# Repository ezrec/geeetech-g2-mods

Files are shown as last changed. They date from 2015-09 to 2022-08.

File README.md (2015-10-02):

# Geeetech Delta Rostock G2/G2s

## OpenSCAD versions of Geeetech STLs (Geeetech)

`geeetech_rostock_g2_jhead_x1.scad` - Upper and lower brackets for G2
`geeetech_rostock_g2_jhead_x2.scad` - Upper and lower brackets for G2s
`geeetech_rostock_g2_spider.scad` - Spider (with optional Z-Probe)
`geeetech_rostock_g2_lock_ring.scad` - Z-Probe lock ring

## Mechanics Modifications

`rod_end_shim.scad` - Shim washers to remove slop in the rod-end mounts

## MK8 Extruder Modifications

`mk8_extruder_guide.scad` - Snap-in guide for the lower feed of the MK8 Extruder

## Alternative Spider Effectors

`cimera-spider.scad` - Spider for E3D Chimera/Cyclops hot ends

## Fan Ducts

`e3d_v6_fan_duct.scad` - Hot-air fan duct for a E3D v6 or v6Lite mounted on a G2 Spider
`universal_fan_duct.scad` - Universal cool-air fan duct for E3D v6 or J-Head, single or dual mount - mounts instead of Z-Probe switch!

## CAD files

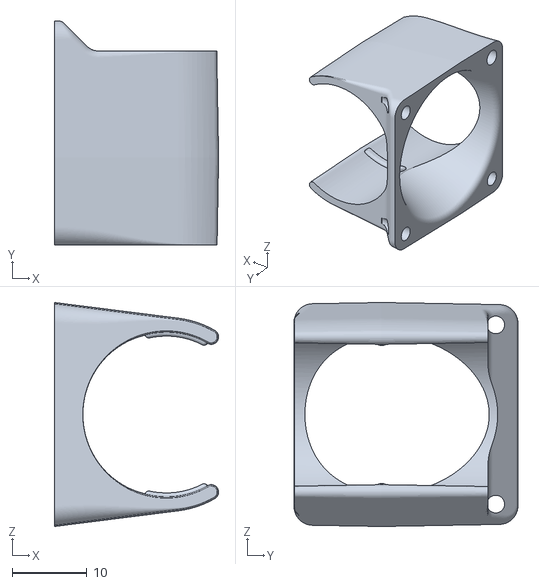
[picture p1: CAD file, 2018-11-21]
E3D/V6.6_Duct.stl
22.0 x 30.0 x 30.0

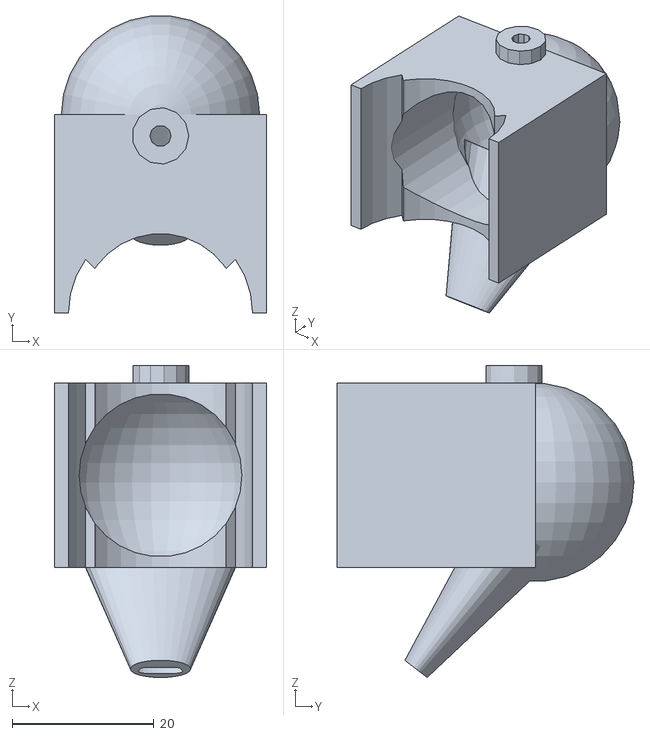
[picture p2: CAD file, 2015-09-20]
e3d_v6_fan_duct.stl
30.0 x 41.9 x 44.1

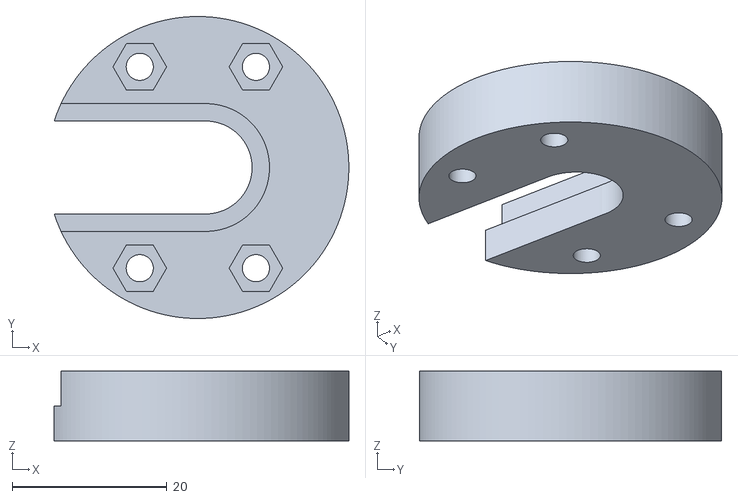
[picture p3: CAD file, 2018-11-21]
Geeetech/G2/GTH3-B01-02-Mount.STL
38.0 x 39.0 x 9.00

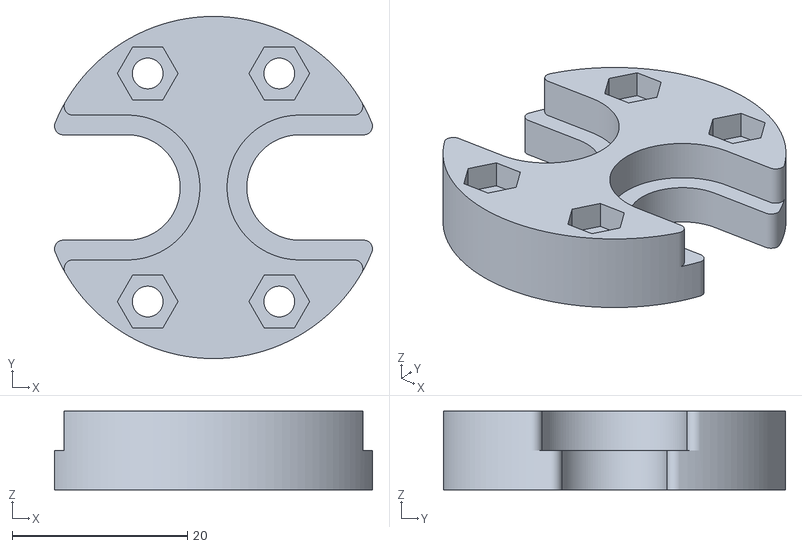
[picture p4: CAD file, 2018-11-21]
Geeetech/G2s/GTH3-B02-02-Mount.STL
36.2 x 39.0 x 9.00

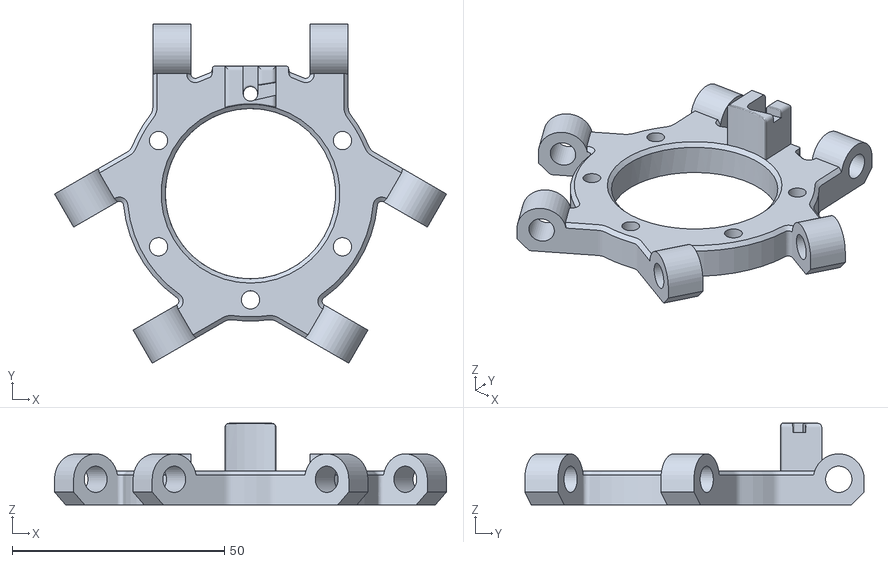
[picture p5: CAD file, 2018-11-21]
Geeetech/RKMA-B02-platform.STL
92.3 x 79.9 x 19.2

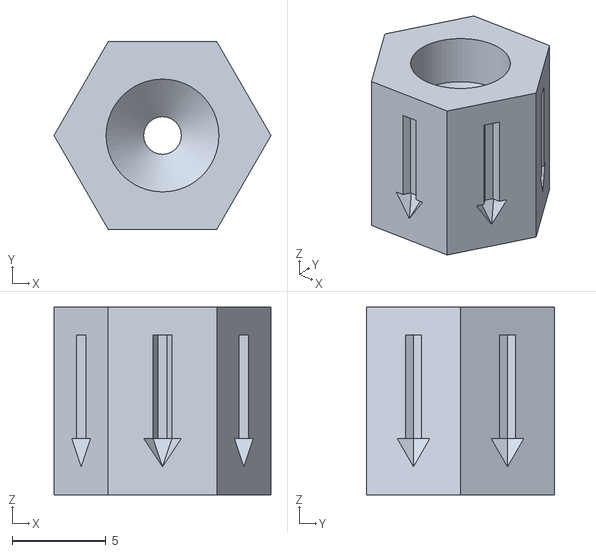
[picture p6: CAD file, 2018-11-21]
stl/ptfe_splicer.stl
11.5 x 10.0 x 10.0

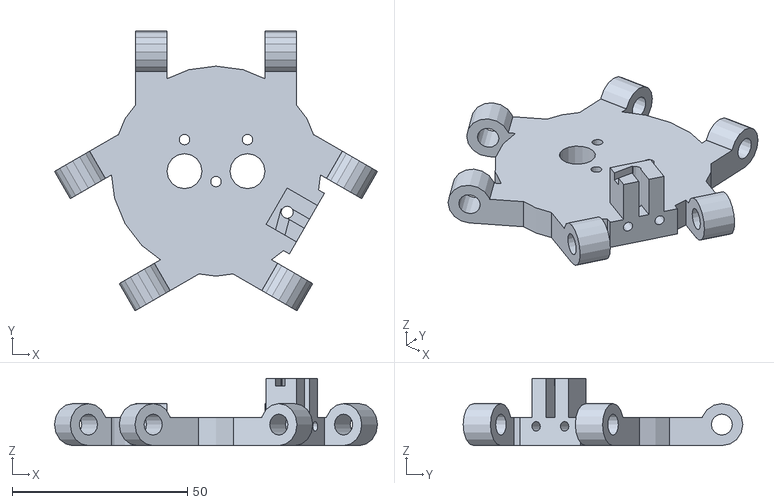
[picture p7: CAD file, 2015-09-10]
chimera-spider.stl
92.3 x 79.9 x 19.2

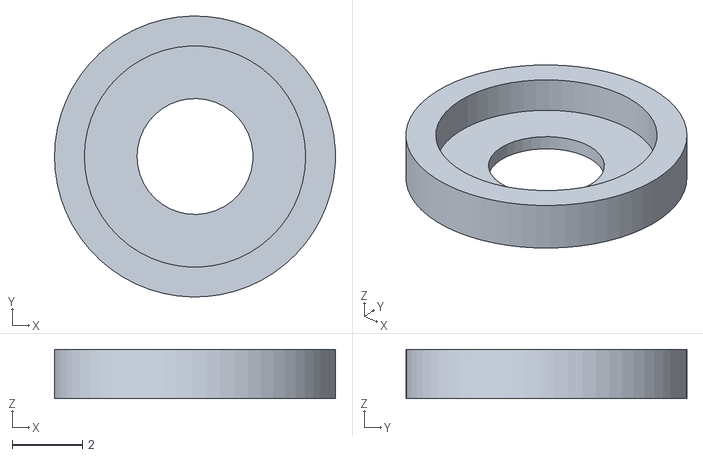
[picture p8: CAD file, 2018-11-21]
Geeetech/G2/RKMC-B01-check ring.STL
8.00 x 8.00 x 1.40

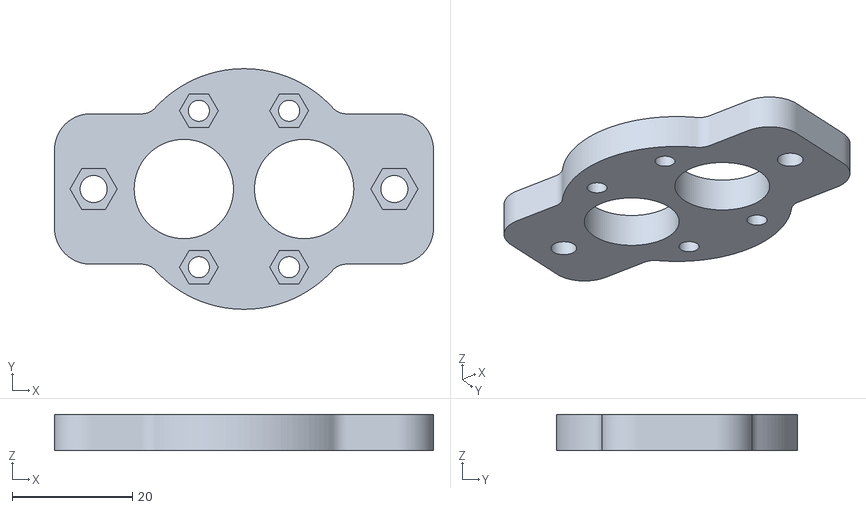
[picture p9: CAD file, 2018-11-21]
Geeetech/G2s/GTH3-B02-01-Mount.STL
63.0 x 40.0 x 6.00

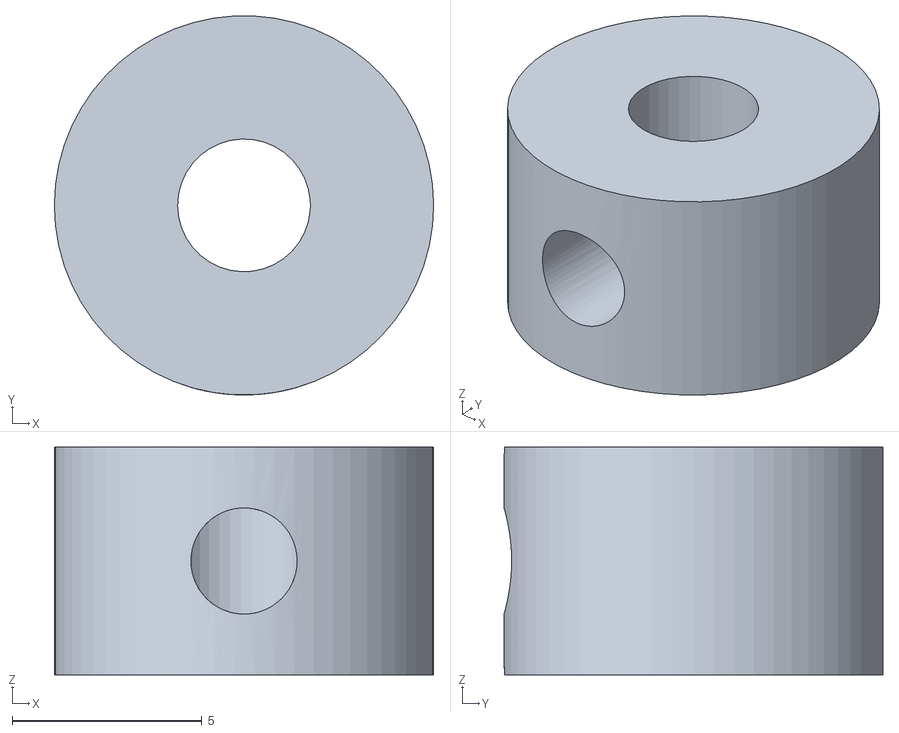
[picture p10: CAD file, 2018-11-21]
Geeetech/RKMA-B05-Lock rings.STL
10.0 x 9.99 x 6.00

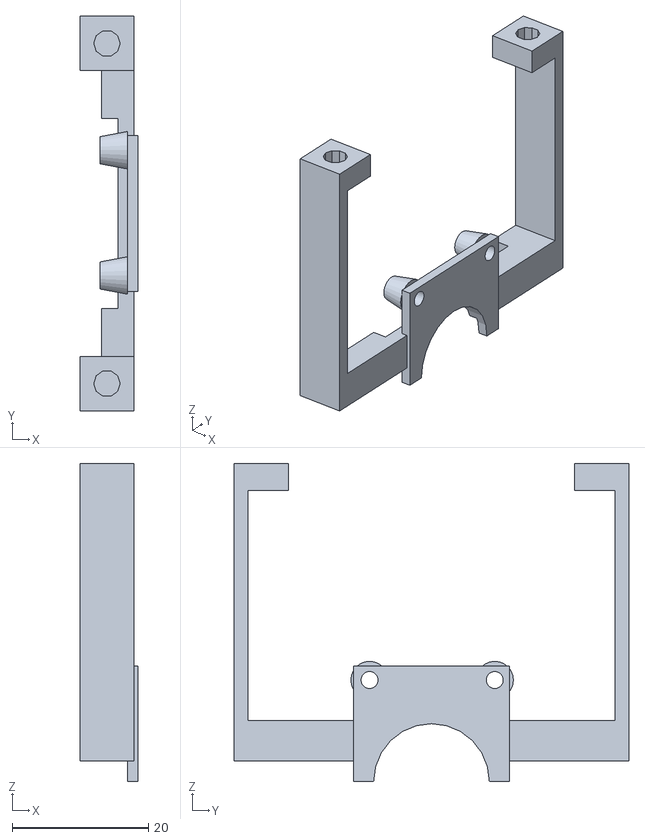
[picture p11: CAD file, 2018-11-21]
stl/universal_probe.stl
8.60 x 58.0 x 46.8

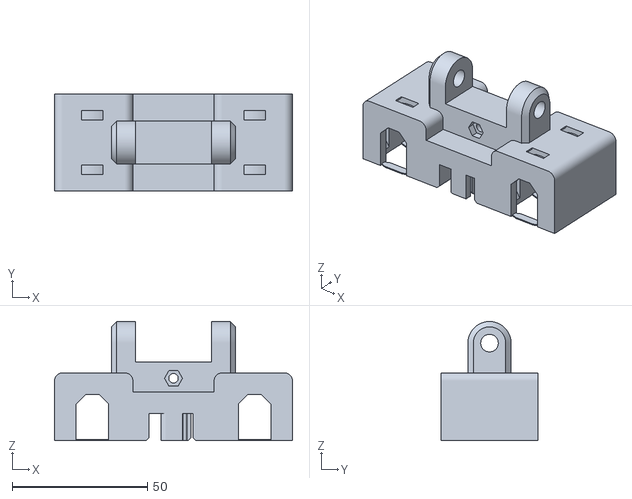
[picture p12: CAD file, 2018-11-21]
Geeetech/RKMA-B01-carriage.STL
88.0 x 36.0 x 44.0

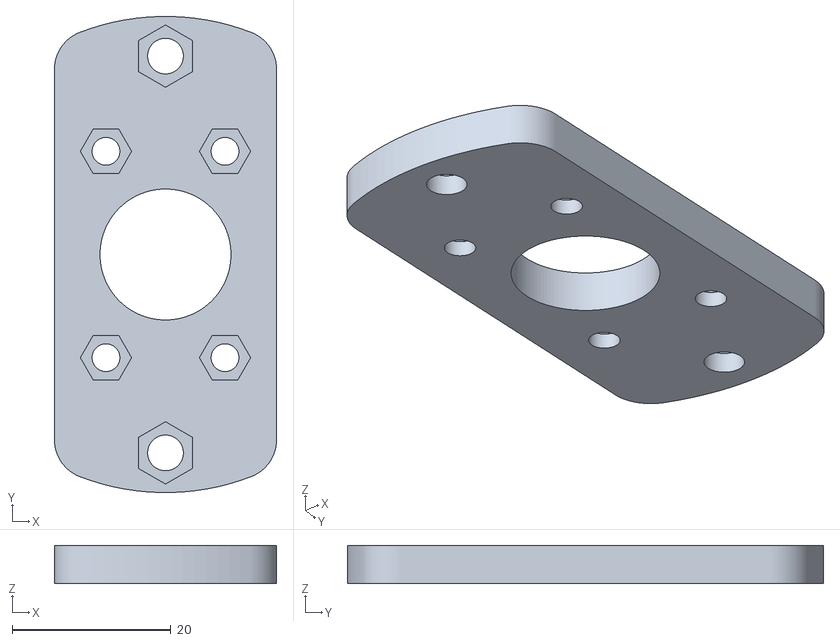
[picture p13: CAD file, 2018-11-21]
Geeetech/G2/GTH3-B01-01-Mount.STL
28.0 x 60.0 x 4.80

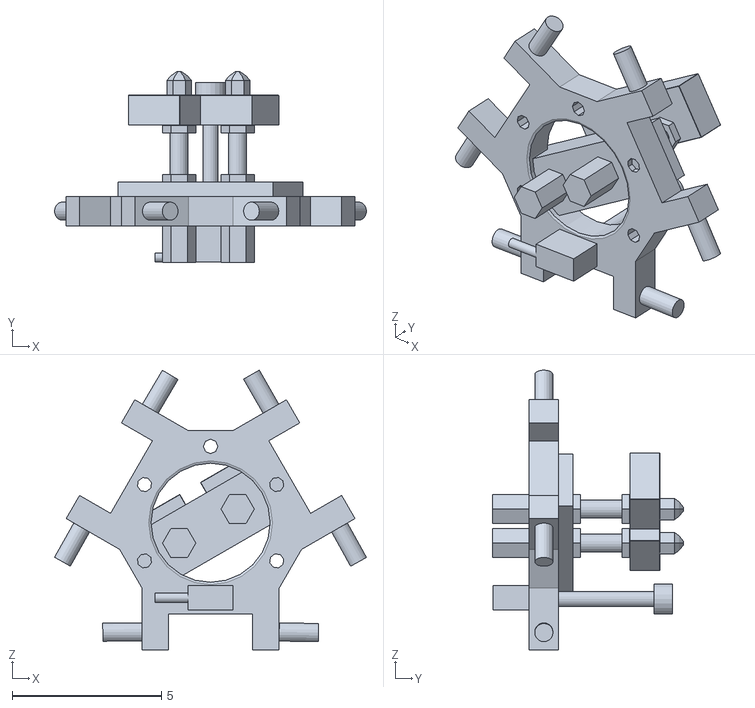
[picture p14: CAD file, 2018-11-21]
Geeetech/PRO_SPIDER.stl
10.5 x 6.41 x 9.37

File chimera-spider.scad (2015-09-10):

//
// Copyright (C) 2015, Jason S. McMullan <jason.mcmullan@gmail.com>
// All right reserved.
//
// Licensed under the MIT License:
//
// Permission is hereby granted, free of charge, to any person obtaining
// a copy of this software and associated documentation files (the "Software"),
// to deal in the Software without restriction, including without limitation
// the rights to use, copy, modify, merge, publish, distribute, sublicense,
// and/or sell copies of the Software, and to permit persons to whom the
// Software is furnished to do so, subject to the following conditions:
//
// The above copyright notice and this permission notice shall be included
// in all copies or substantial portions of the Software.
//
// THE SOFTWARE IS PROVIDED "AS IS", WITHOUT WARRANTY OF ANY KIND, EXPRESS OR
// IMPLIED, INCLUDING BUT NOT LIMITED TO THE WARRANTIES OF MERCHANTABILITY,
// FITNESS FOR A PARTICULAR PURPOSE AND NONINFRINGEMENT. IN NO EVENT SHALL THE
// AUTHORS OR COPYRIGHT HOLDERS BE LIABLE FOR ANY CLAIM, DAMAGES OR OTHER
// LIABILITY, WHETHER IN AN ACTION OF CONTRACT, TORT OR OTHERWISE, ARISING
// FROM, OUT OF OR IN CONNECTION WITH THE SOFTWARE OR THE USE OR OTHER
// DEALINGS IN THE SOFTWARE.
//

include <E3D/chimera.scad>
include <Geeetech/rostock_g2_spider.scad>

module geeetech_spider_e3d_chimera(zprobe = true)
{
    difference() {
        union() {
            rotate([0, 0, 240])
            geeetech_rostock_g2_spider_blank(zprobe);
        }
        translate([-9, 0, -0.1])
            cylinder(d=10, h=10, $fn=16);
        translate([9, 0, -0.1])
            cylinder(d=10, h=10, $fn=16);
        translate([0, -3, -0.1])
            cylinder(d=3, h=10, $fn=16);
        translate([-9, 9, -0.1])
            cylinder(d=3, h=10, $fn=16);
        translate([9, 9, -0.1])
            cylinder(d=3, h=10, $fn=16);
    }

    % translate([-15, -6, 0])     e3d_v6_chimera();
}


geeetech_spider_e3d_chimera();

// vim: set shiftwidth=4 expandtab: //

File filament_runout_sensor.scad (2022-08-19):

//
// Copyright 2019 Barrett Ford <https://www.thingiverse.com/barrettford/about>
//
// https://www.thingiverse.com/thing:3052714
//

$fa=.5;
$fs=1;
$fn=60;

module switch() {
  difference() {
    union() {
      translate([0,-3.3,0]) cube([10, 6.6, 9.5]);
      translate([-10,-3.3,0]) cube([10, 6.6, 10.3]);
      
      translate([-7,-3.3,10.5]) rotate([0,70,0]) cube([7, 6.6, 21]);
    }
    translate([5, 4, 2.6]) rotate([90,0,0]) cylinder(d=3,h=8);
    translate([-5, 4, 2.6]) rotate([90,0,0]) cylinder(d=3,h=8);
  }
  hull() {
    translate([10.7 , 3.3, 15.5]) rotate([90,0,0]) cylinder(d=5,h=6.6);
    translate([10.35, 3.3, 17.0]) rotate([90,0,0]) cylinder(d=5,h=6.6);
    translate([10.0 , 3.3, 18.5]) rotate([90,0,0]) cylinder(d=5,h=6.6);
    translate([9.65 , 3.3, 19.5]) rotate([90,0,0]) cylinder(d=5,h=6.6);
  }
}


module bottom() {
  height = 9;
  tube_diameter = 4.2;
  difference() {
    union() {
      translate([1.5,0,0]) hull()
      {
        translate([-12,5.5,2.5])  rotate([90,0,0]) cylinder(d=5, h=height);
        translate([ 12,5.5,2.5])  rotate([90,0,0]) cylinder(d=5, h=height);
        translate([-18,5.5,27.5]) rotate([90,0,0]) cylinder(d=5, h=height);
        translate([ 18,5.5,27.5]) rotate([90,0,0]) cylinder(d=5, h=height);
        
      }
    }
    translate([-25,0,25]) rotate([0,90,0]) cylinder(d=tube_diameter, h=50);
    translate([-11,-6.5,-1]) cube([22, 10, 21]);
    translate([ 5,-6.5, 10]) cube([11, 10, 16]);
    
    hull() {
      translate([5, 6, 3.6]) rotate([90,0,0]) cylinder(d=3,h=20);
      translate([5, 6, 10]) rotate([90,0,0]) cylinder(d=3,h=20);
    }
    
    hull() {
      translate([-5, 6, 3.6]) rotate([90,0,0]) cylinder(d=3,h=20);
      translate([-5, 6, 10]) rotate([90,0,0]) cylinder(d=3,h=20);
    }
  }
}

// Uncomment this line to see where the switch would fit
//translate([0,0,5]) #switch();
bottom();

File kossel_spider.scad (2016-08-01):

//
// Copyright (C) 2016, Jason S. McMullan <jason.mcmullan@gmail.com>
// All rights reserved.
//
// Generic Kossel effector.
//
// Licensed under the MIT License:
//
// Permission is hereby granted, free of charge, to any person obtaining
// a copy of this software and associated documentation files (the "Software"),
// to deal in the Software without restriction, including without limitation
// the rights to use, copy, modify, merge, publish, distribute, sublicense,
// and/or sell copies of the Software, and to permit persons to whom the
// Software is furnished to do so, subject to the following conditions:
//
// The above copyright notice and this permission notice shall be included
// in all copies or substantial portions of the Software.
//
// THE SOFTWARE IS PROVIDED "AS IS", WITHOUT WARRANTY OF ANY KIND, EXPRESS OR
// IMPLIED, INCLUDING BUT NOT LIMITED TO THE WARRANTIES OF MERCHANTABILITY,
// FITNESS FOR A PARTICULAR PURPOSE AND NONINFRINGEMENT. IN NO EVENT SHALL THE
// AUTHORS OR COPYRIGHT HOLDERS BE LIABLE FOR ANY CLAIM, DAMAGES OR OTHER
// LIABILITY, WHETHER IN AN ACTION OF CONTRACT, TORT OR OTHERWISE, ARISING
// FROM, OUT OF OR IN CONNECTION WITH THE SOFTWARE OR THE USE OR OTHER
// DEALINGS IN THE SOFTWARE.
//
// All units are in mm

// Adjust the scaler for quick twist lock tolerance-only prints 
scaler = 1;

/* [Delta Geometry] */

// Distance from center of effector to center of diagnal rod axis
effector_radius = 34; // [10:100]

// Distance between effector rod ends
effector_width = 46; // [10:100]

// Height of the effector frame
effector_height = 8;

/* [Diagonal Rod Mount] */

// Diameter of the rod end holder
effector_holder_diameter = 6; // [1:20]

// Width of the wall of the rod end holder
effector_holder_wall = 3.5; // [1:10]

// Length of the rod end holder hole
effector_holder_hole = 9; // [1:20]

/* [Effector Mount] */

// Flat-to-flat diameter of the internal hex mount
effector_mount_hex = 40; // [0:100]

/* [Hotend Lock] */

// Hotend model
hotend_model=0; // [0:E3D v6,1:J-Head,2:Custom Groovemount]

// Minimum wall size around the hotend in mm
hotend_wall = 2; // [1:5]

// Hotend bulk diameter
custom_hotend_diameter = 20;
custom_hotend_height = 30;
custom_hotend_groove_diameter = 12;
custom_hotend_groove_height = 3;
custom_hotend_inlet_diameter = 16;
custom_hotend_shoulder_diameter = 16;
custom_hotend_shoulder_height = 6;

// E3D v6
e3dv6_hotend_diameter = 22;
e3dv6_hotend_height = 31.5;
e3dv6_hotend_groove_diameter = 12;
e3dv6_hotend_groove_height = 6;
e3dv6_hotend_inlet_diameter = 16;
e3dv6_hotend_shoulder_diameter = 16;
e3dv6_hotend_shoulder_height = 6;

// J-Head
jhead_hotend_diameter = 16;
jhead_hotend_height = 29;
jhead_hotend_groove_diameter = 12;
jhead_hotend_groove_height = 4.5;
jhead_hotend_inlet_diameter = 16;
jhead_hotend_shoulder_diameter = 16;
jhead_hotend_shoulder_height = 0;

hotend_diameter = (hotend_model == 0 ? e3dv6_hotend_diameter :
                  (hotend_model == 1 ? jhead_hotend_diameter :
                   custom_hotend_diameter));
hotend_height =  (hotend_model == 0 ? e3dv6_hotend_height :
                 (hotend_model == 1 ? jhead_hotend_height :
                  custom_hotend_height));
hotend_groove_diameter = (hotend_model == 0 ? e3dv6_hotend_groove_diameter :
                 (hotend_model == 1 ? jhead_hotend_groove_diameter :
                  custom_hotend_groove_diameter));
hotend_groove_height = (hotend_model == 0 ? e3dv6_hotend_groove_height :
                 (hotend_model == 1 ? jhead_hotend_groove_height :
                  custom_hotend_groove_height));
hotend_inlet_diameter = (hotend_model == 0 ? e3dv6_hotend_inlet_diameter :
                 (hotend_model == 1 ? jhead_hotend_inlet_diameter :
                  custom_hotend_inlet_diameter));
hotend_shoulder_diameter = (hotend_model == 0 ? e3dv6_hotend_shoulder_diameter :
                 (hotend_model == 1 ? jhead_hotend_shoulder_diameter :
                  custom_hotend_shoulder_diameter));
hotend_shoulder_height = (hotend_model == 0 ? e3dv6_hotend_shoulder_height :
                 (hotend_model == 1 ? jhead_hotend_shoulder_height :
                  custom_hotend_shoulder_height));


hotend_radius = hotend_diameter/2;

hotend_lock_brim = 1.5; // [0.25:5]
hotend_lock_height = effector_height - hotend_wall*2;

// Critical dimensions of the lock - 'maximum' lock size
hotend_lock_radius   = e3dv6_hotend_diameter/2+hotend_wall;
hotend_lock_distance = e3dv6_hotend_diameter+hotend_wall;

/* [Fan Dimensions] */
fan_width = 30; // [10:40]

/* [ Global ] */

// Screw size
screw_width = 2.6;
screw_depth = 5.75;
screw_gap = 24.5;

// Twist-lock lock_tolerance
lock_tolerance = 0.25 / scaler;
// Hole tolerance
hole_tolerance = 0.125 / scaler;

// Faces for cylinders
fn = 60; // [6:60]

fan_radius = fan_width/2-hotend_wall;

// WhosaWhatsis Hull Chain
module hull_chain()
{
    for (i = [0 : $children - 2]) hull() for(j = [i, i+1]) children(j);
}


module round_hole(r = 1, h = 1, centered = false, fn = fn)
{
    if (centered) {
        translate([0, 0, -h/2-0.1])
            cylinder(r = r + hole_tolerance, h = h + 0.2, $fn = fn);
    } else {
        translate([0, 0, -0.1])
            cylinder(r = r + hole_tolerance, h = h + 0.2, $fn = fn);
    }
}

// 2D Measurement graphic
module measure(distance = 5, unit = "n")
{
    thickness = 0.2;
    length = 2;
    text_height = 1;
    text_length = 3;

    text(str(distance,unit), halign = "center", valign = "bottom", size = text_height);
}

module hotend_cut(tolerance = lock_tolerance)
{
    translate([0, 0, -0.1])
    rotate_extrude(angle = 360, $fn = fn) {
        intersection() {
            offset(delta = tolerance, chamfer = true) {
                /* Build radius profile of hotend from bottom up */
                
                /* Body */
                square([hotend_radius, hotend_height-hotend_shoulder_height+0.1]);
                translate([0, hotend_height-hotend_shoulder_height+0.1]) {
                    square([hotend_shoulder_diameter/2, hotend_shoulder_height]);
                    translate([0, hotend_shoulder_height]) {
                        square([hotend_groove_diameter/2, hotend_groove_height+0.01]);
                        translate([0, hotend_groove_height+0.01])
                            square([hotend_inlet_diameter/2, hotend_wall*2]);
                    }
                }
            }
            translate([0, -1]) square([100, 100]);
        }
    }
}

module twist_lock_base(r = hotend_radius, d = hotend_lock_distance, h = hotend_lock_height, height = hotend_height, wall = hotend_wall, brim = hotend_lock_brim, lock_tolerance = lock_tolerance)
{
    hull() {
        for (i=[-d/2:d:d/2])
            translate([i, 0, 0]) cylinder(r = hotend_lock_radius + brim + lock_tolerance, h = h, $fn = fn);
    }
    
    hull() {
        for (i=[-d/2:d:d/2])
            translate([i, 0, 0]) cylinder(r = hotend_lock_radius + lock_tolerance, h = height + hotend_groove_height, $fn = fn);
    }
}

module twist_fan_sketch(delta = 0)
{
    r = hotend_radius;
    d = hotend_lock_distance;
    wall = hotend_wall;
    
    offset(delta = delta, chamfer = true) {
        hull() {
            for (i=[-d/2:d:d/2])
                translate([i, 0])
                    circle(r = r + wall + lock_tolerance + wall, $fn = fn);
        }
        if (delta >= 0) {
            width = r+wall+lock_tolerance+screw_depth;
            translate([-fan_width/2,-width])
                square([fan_width, width]);
        }
    }
}

module twist_fan_x1(r = hotend_radius, d = hotend_lock_distance, h = hotend_lock_height, height = hotend_height, wall = hotend_wall, brim = hotend_lock_brim, lock_tolerance = lock_tolerance)
{
    difference() 
    {
        union() {
            translate([0, 0, h + wall*2 + lock_tolerance])
                linear_extrude(height = height - h + hotend_groove_height + lock_tolerance)
                    twist_fan_sketch(delta = 0);
        }
        
        // Interior cut
        translate([0, 0, -0.1])
            linear_extrude(height =  height-wall + h + hotend_groove_height+lock_tolerance*2 + 0.1)
                twist_fan_sketch(delta = - wall);
        
        // Top cut
        hull() {
            for (i=[-d/2:d:d/2]) {
                translate([i, 0, h + lock_tolerance + height-wall + hotend_groove_height])
                    round_hole(r = hotend_inlet_diameter/2, h = wall + lock_tolerance*2);
            }
        }
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

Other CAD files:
Geeetech/G2/RKMA-B06-Mount.STL
stl/geeetech_rostock_g2_jhead_x2_upper.stl
stl/jhead_lock_x2.stl
Geeetech/G2/RKMA-B04--Mount.STL
e3d_chimera_spider.scad
E3D/chimera.scad
E3D/utility.scad
E3D/v6_block.scad
E3D/v6_break.scad
E3D/v6_lite.scad
E3D/v6_nozzle.scad
Geeetech/LCD2004A.scad
Geeetech/RKMA-B03-FanH.STL
Geeetech/extruder_mk8_drill.scad
Geeetech/jhead_peek.scad
Geeetech/rostock_g2_bed.scad
Geeetech/rostock_g2_carriage.scad
Geeetech/rostock_g2_jhead_x1.scad
Geeetech/rostock_g2_jhead_x2.scad
Geeetech/rostock_g2_lock_ring.scad
Geeetech/rostock_g2_lock_ring.stl
Geeetech/rostock_g2_pulleys.scad
Geeetech/rostock_g2_spider.scad
Geeetech/rostock_g2_spider_no_probe.stl
Geeetech/rostock_g2_spider_z_probe.stl
Geeetech/rostock_pro_spider.scad
Geeetech/utility.scad
blower_40mm.scad
e3d_v6_mount.scad
evillabs.scad
fan_bed_clip.scad
mcspider.scad
mini_height_sensor.scad
mk8_extruder_guide.scad
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

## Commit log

2015-09-10 Initial import of Geeetech Delta Rostock G2/G2s spider effector developemnt
    [chimera.scad, rostock_g2_spider.scad, utility.scad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]
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2015-09-10 E3D: Add rudimentary fan model ghost to the chimera
    [chimera.scad, utility.scad]
2015-09-10 Geeetech/rostock_g2_spider: Add (optional) zprobe mount
    [rostock_g2_spider.scad]
2015-09-10 chimera-spider: Re-render with zprobe mount
    Also, re-orient so that the hotend maintainance bolts face the front
    [chimera-spider.scad, chimera-spider.stl]
2015-09-10 G2s: Start work on JHead mount for the G2s
    [rostock_g2_jhead_x2.scad]
2015-09-11 Filament guide for the Geeetech MK8 Extruder
    No more cursing trying to feed in the filament!
    [mk8_extruder_guide.scad, mk8_extruder_guide.stl]
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2015-09-14 E3D/utility: Add 'hanoi' hack to make generating heat sinks easier
    [utility.scad]
2015-09-14 E3D/v6_lite: Add model for the e3d_v6_lite heat sink
    [v6_lite.scad]
2015-09-20 E3D: Clean up some v6 origin/children issues
    [v6_block.scad, v6_lite.scad, v6_nozzle.scad]
2015-09-20 Geeetech: Add G2/G2s spider STL models
    [rostock_g2_spider_no_probe.stl, rostock_g2_spider_z_probe.stl]
2015-09-20 e3d_v6_fan_duct: Add fan duct add-on for E3D v6 Lite
    Uses an open 4mm bolt hole in the G2/G2s spider for attachment
    [e3d_v6_fan_duct.scad, e3d_v6_fan_duct.stl]
2015-09-20 e3d_v6_fan_duct: Update STL to match SCAD
    [e3d_v6_fan_duct.stl]
2015-09-20 rod_end_shim.stl: Add rod-end shims
    Used to eliminate slop in the rod-end bearings
    [rod_end_shim.scad, rod_end_shim.stl]
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2015-09-22 Geeetech/rostock_g2_bed: Model of the G2/G2s aluminum bed plate
    [rostock_g2_bed.scad]
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2015-09-23 Add Geeetech G2/G2s Z-Probe lock ring models
    [rostock_g2_lock_ring.scad, rostock_g2_lock_ring.stl]
2015-09-23 Geeetech: Add spider bracket for G2 single-extruder mount
    [rostock_g2_spider.scad, rostock_g2_spider_bracket.scad, rostock_g2_spider_bracket.stl]
2015-09-23 Add G2s spider extruder bracket
    [rostock_g2s_spider_bracket.scad, rostock_g2s_spider_bracket.stl]
2015-09-23 Build: Move all the STL files to the 'stl' directory
    [e3d_chimera_spider.scad, e3d_chimera_spider_no_probe.stl, e3d_chimera_spider_z_probe.stl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]
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2015-09-25 Makefile: Use 'use' instead of concatenating included files
    [e3d_v6_fan_duct.stl, geeetech_rostock_g2_lock_ring.stl, mk8_extruder_guide.stl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]
2015-09-25 Geeetech: Add utility functions for mitred boxes and torus
    Eliminates some computationally expensive (and hard to align)
    minkowski() sums.
    [e3d_chimera_spider_no_probe.stl, e3d_chimera_spider_z_probe.stl, geeetech_rostock_g2_jhead_x1_lower.stl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]
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2015-09-27 E3D/v6_lite: Update to match the PEEK J-head origin/children
    [e3d_v6_fan_duct.scad, rostock_g2_jhead_x2.scad, v6_lite.scad]
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2015-09-28 jhead_x2_fan_duct: Work in progress
    Issues:
    * Blower position interferes with rods
    * Insufficiently parameterized
    * Interferes (by 0.5mm) with JHead #2's heat block
    [jhead_x2_fan_duct.scad, jhead_x2_fan_duct.stl]
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2015-10-02 universal_fan_duct: Modify jhead_x2_fan_duct to work for E3D also.
    * Adjustable bolt slots to raise or lower for 35mm to 45mm heights
    * Blower is now out of the way of the diagonal rods
    * Printable with no bridging required
    * Improved parameterization
    * Wider and angled duct output
    [jhead_x2_fan_duct.scad, universal_fan_duct.scad, universal_fan_duct.stl]
2015-10-19 E3D v6 Mount: Add E3D v6 mount designs for the Geeetech spider
    NOTE: The hot end fan ducts on E3D v6 x2 mount will need to be
    mounted facing each other, for now.
    [e3d_v6_mount.scad, e3d_v6_x1_mount_lower.stl, e3d_v6_x1_mount_upper.stl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]
2015-10-23 Geeetech G2 - Update tolerances for the GrooveMount
    Should be easier to fit into the spider, and hold the E3D v6 more firmly
    [geeetech_rostock_g2_jhead_x1_lower.stl, geeetech_rostock_g2_jhead_x1_upper.stl, geeetech_rostock_g2_jhead_x2_lower.stl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]
2015-11-20 e3d_v6: Add alternate spider design for 2x E3D v6 devices
    [e3d_v6_mount.scad, e3d_v6_x2_lock.stl, e3d_v6_x2_spider.stl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]
2015-11-24 e3d_v6_mount: New 'friction fit' spider prototype
    Supports both x1 and x2 E3D with the same spider, but different
    locks.
    Spider is mounted 'upside down' and the lock is pressed in from underneath.
    [e3d_v6_mount.scad, e3d_v6_spider.stl, e3d_v6_x1_lock.stl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]
2015-12-11 Geetech/utility.scad: Correct mitred torus top
    [utility.scad]
2015-12-11 WIP: E3D v6 new fan duct and probe
    [e3d_v6_fan_duct.scad, e3d_v6_probe.scad, mini_height_sensor.scad]
2015-12-30 E3D v6: Continuing work on the new spider
    [e3d_chimera_spider_no_probe.stl, e3d_chimera_spider_z_probe.stl, e3d_v6_fan_duct.scad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]
2015-12-30 rod_end_shim.scad: Draw as a ring, instead of as a grid
    [rod_end_shim.scad, rod_end_shim.stl]
2015-12-30 Universal spider - snap-fit spider for x1 or x2 E3D v6 or J-Heads
    x2 spread is 30mm from nozzle to nozzle.
    [e3d_v6_spider.stl, jhead_lock_x1.stl, jhead_lock_x2.stl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]
2016-01-31 e3d_v6_fan_duct: Multi-piece duct 'system' for the E3Dv6 on a G2/G2s
    [e3d_v6_fan_duct.scad]
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2016-03-31 rostock_pro_spider: Fix build of the spider
    [geeetech_rostock_pro_spider.stl, rostock_pro_spider.scad]
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2016-03-31 universal effector: WIP checkin, using the larger fan duct
    [e3d_v6_fan_duct.scad, e3d_v6_fan_duct.stl, e3d_v6_lock_x1.stl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]
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2016-06-15 kossel_spider: Add locking ridge, and make a generalized hotend cutout
    [kossel_spider.scad]
2016-06-15 universal_fan_duct: Make 'foot' sloped, to stay out of the way
    [universal_fan_duct.scad, universal_fan_duct_assembly.scad]
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2016-07-19 ptfe_splicer: Add part to splice between two PTFE connectors
    [ptfe_splicer.scad, ptfe_splicer.stl]
2016-08-01 mcspider: Work in progress for a new twist-lock spider
    [mcspider.scad, mcspider_effector.stl, mcspider_foot.stl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]
2016-08-01 kossel_spider: Design failed - hotend block overheats the effector causing deformation and loss of calibration.
    [kossel_spider.scad]
2016-08-01 mcspider: Minor cleanups
    * Effector can now be inserted from top or bottom
    * Refined gap between lock halves
    * Increased bulk of foot half of lock to reduce breakage during locking
    * Positioning issues with x2 lock
    [mcspider.scad, mcspider_effector.stl, mcspider_foot.stl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]
2018-01-19 Geeetech/rostock_g2_spider: added tapering to the spider leg to ring.
    NOTE: The leg joints on my print broke under stress, hence this re-enforcement.
    May add more weight to the spider.
    [rostock_g2_spider.scad]
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2018-01-21 fan_bed_clip: Add a bed standoff and clip for fans
    [fan_bed_clip.scad]
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
